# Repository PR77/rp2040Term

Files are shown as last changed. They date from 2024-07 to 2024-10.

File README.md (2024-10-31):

# rp2040Term
PR2040 VT100 Terminal with Parallel TFT LCD. Work in progress!

# Warning
This design has not been compliance tested and will not be. It may cause personal damage to you or others. I take no responsibility for this. I accept no responsibility for any damage to any equipment that results from the use of this design and its components. IT IS ENTIRELY AT YOUR OWN RISK!

# Overview
The main purpose of this design was to learn about the RP2040 scanvideo library components and utilise them with a Parallel TFT LCD. Parallel meaning the interface uses HYSNC, VSYNC, DEN (currently not used), PCLK and RGB[5] signals.

I am currently using this with a Sharp LQ042 LCD with a resolution of 480x272. This works perfectly with a 8x16 Font to give a total of 60 Columns by 17 Rows.

# Appearance Breadboard Version
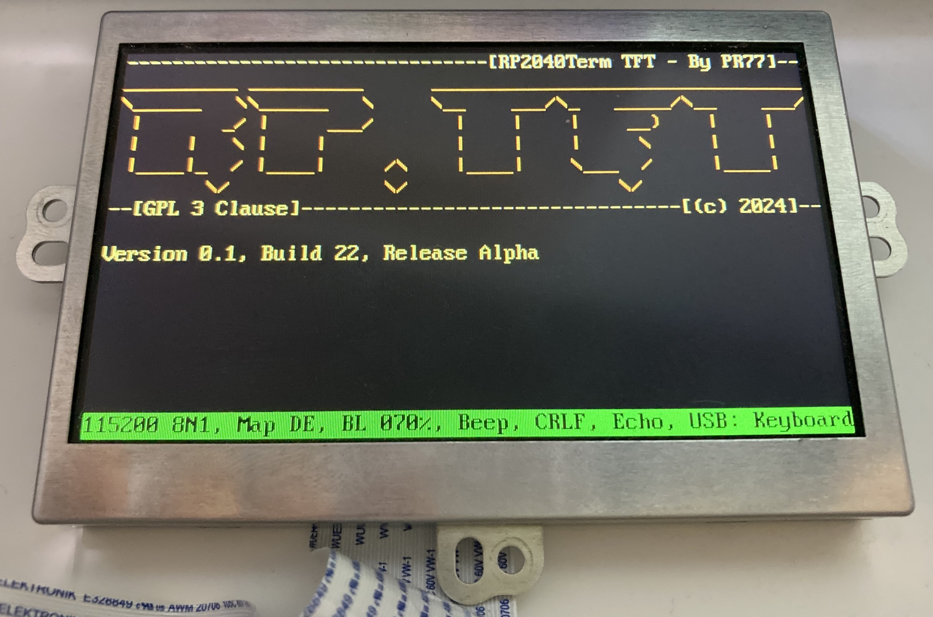
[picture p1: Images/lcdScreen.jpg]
LCD Screen

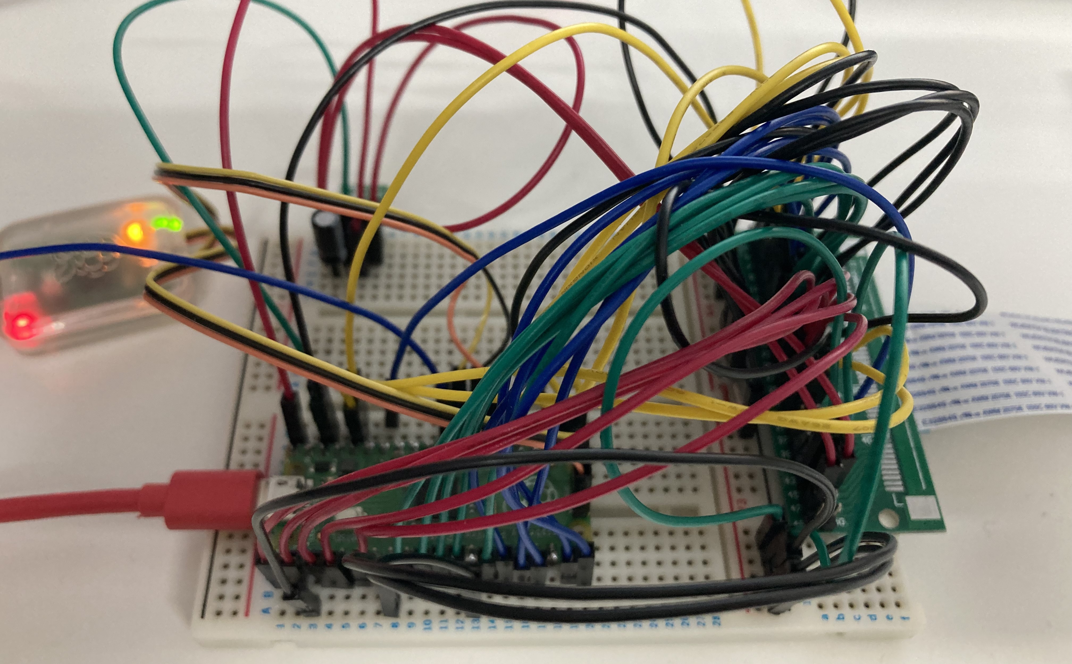
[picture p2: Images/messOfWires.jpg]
Mess Of Wires


# Appearance PCB Version
Here is the 3D render of the general layout. Schematics, gerbers and other support files are now available. A few improvements to the PCB will be made over time, specially I want to add the RP2040 directly to the board and not use a Pi Pico. This iterration is more or less a proof of concept.

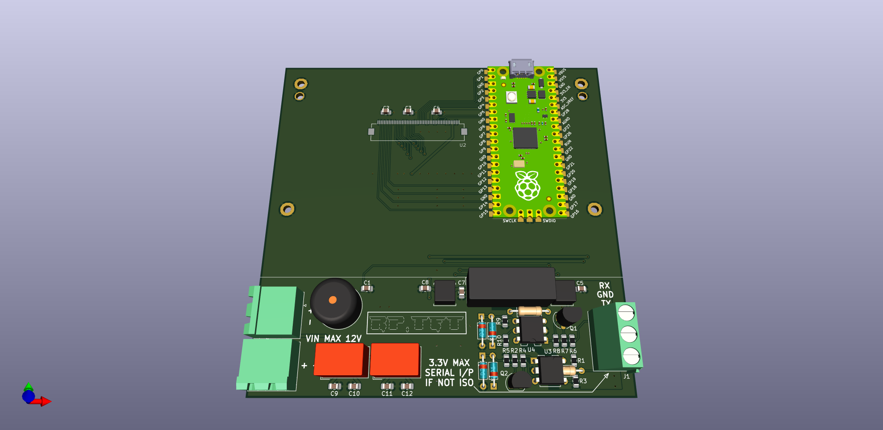
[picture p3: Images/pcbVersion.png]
PCB Layout


# Credits
Repos containing some great tools and resources;
- https://geoffg.net/terminal.html
- https://github.com/Memotech-Bill/pico-colour-text/tree/main
- https://github.com/RC2014Z80/picoterm
- https://github.com/TuriSc/RP2040-PWM-DMA-Audio
- https://github.com/rewtnull/amigafonts
- https://github.com/Jamesits/bin2array

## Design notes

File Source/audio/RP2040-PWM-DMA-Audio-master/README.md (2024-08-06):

# RP2040 PWM/DMA audio

This C library allows playback of audio samples on Raspberry Pi Pico.
It is a fork of Ricardo Massaro's
[pico-audio-demo](https://github.com/moefh/pico-audio-demo), based on an article
by [Greg Chadwick](https://gregchadwick.co.uk/blog/playing-with-the-pico-pt3/).

Please refer to the original code for examples of use.

### Projects using this library
- [Dodepan](https://github.com/TuriSc/Dodepan)

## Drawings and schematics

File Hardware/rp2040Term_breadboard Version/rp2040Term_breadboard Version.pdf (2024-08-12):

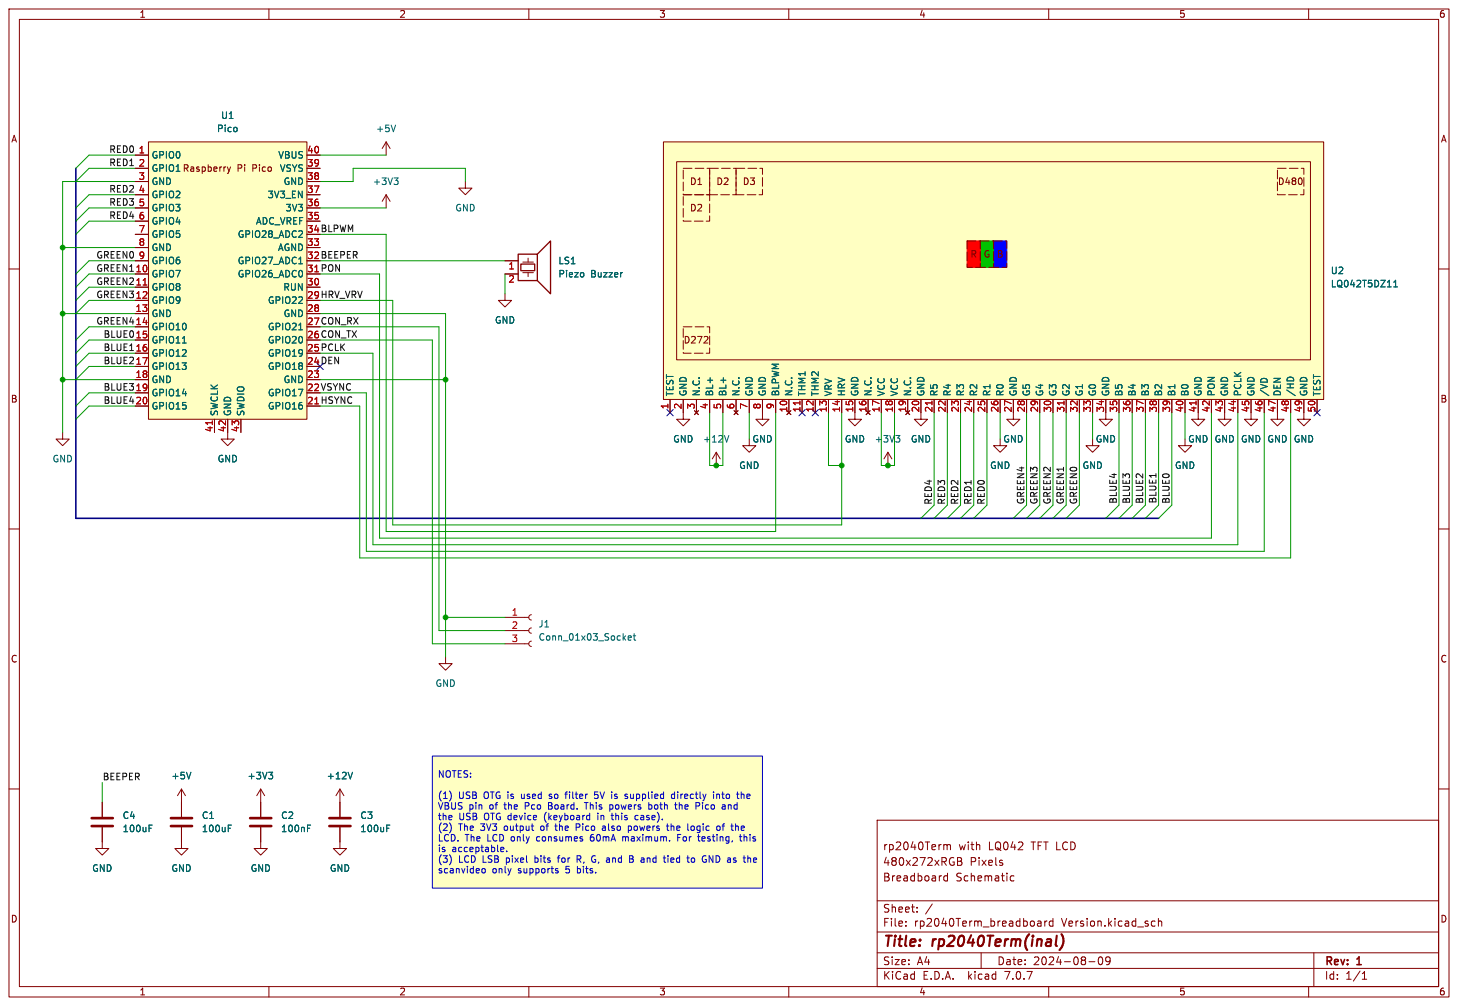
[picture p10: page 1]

1 N.C. 10 THM1 11 THM2 12 VRV 13 HRV 14 GND 15 N.C. 16 VCC 17 VCC 18 N.C. 19 GND

4 B0 40 GND 41 PON 42 GND 43 PCLK 44 GND 45 /VD 46 DEN 47 /HD 48 GND 49 BL+

2 GND 20 R5 21 R4 22 R3 23 R2 24 R1 25 R0 26 GND 27 G5 28 G4 29 N.C. 3 G3 30 G2 31 G1 32 G0 33 GND 34 B5 35 B4 36 B3 37 B2 38 B1 39 BL+

9 GND GND GND GND GND GND GND GND

(2) The 3V3 output of the Pico also powers the logic of the
is acceptable.
(3) LCD LSB pixel bits for R, G, and B and tied to GND as the

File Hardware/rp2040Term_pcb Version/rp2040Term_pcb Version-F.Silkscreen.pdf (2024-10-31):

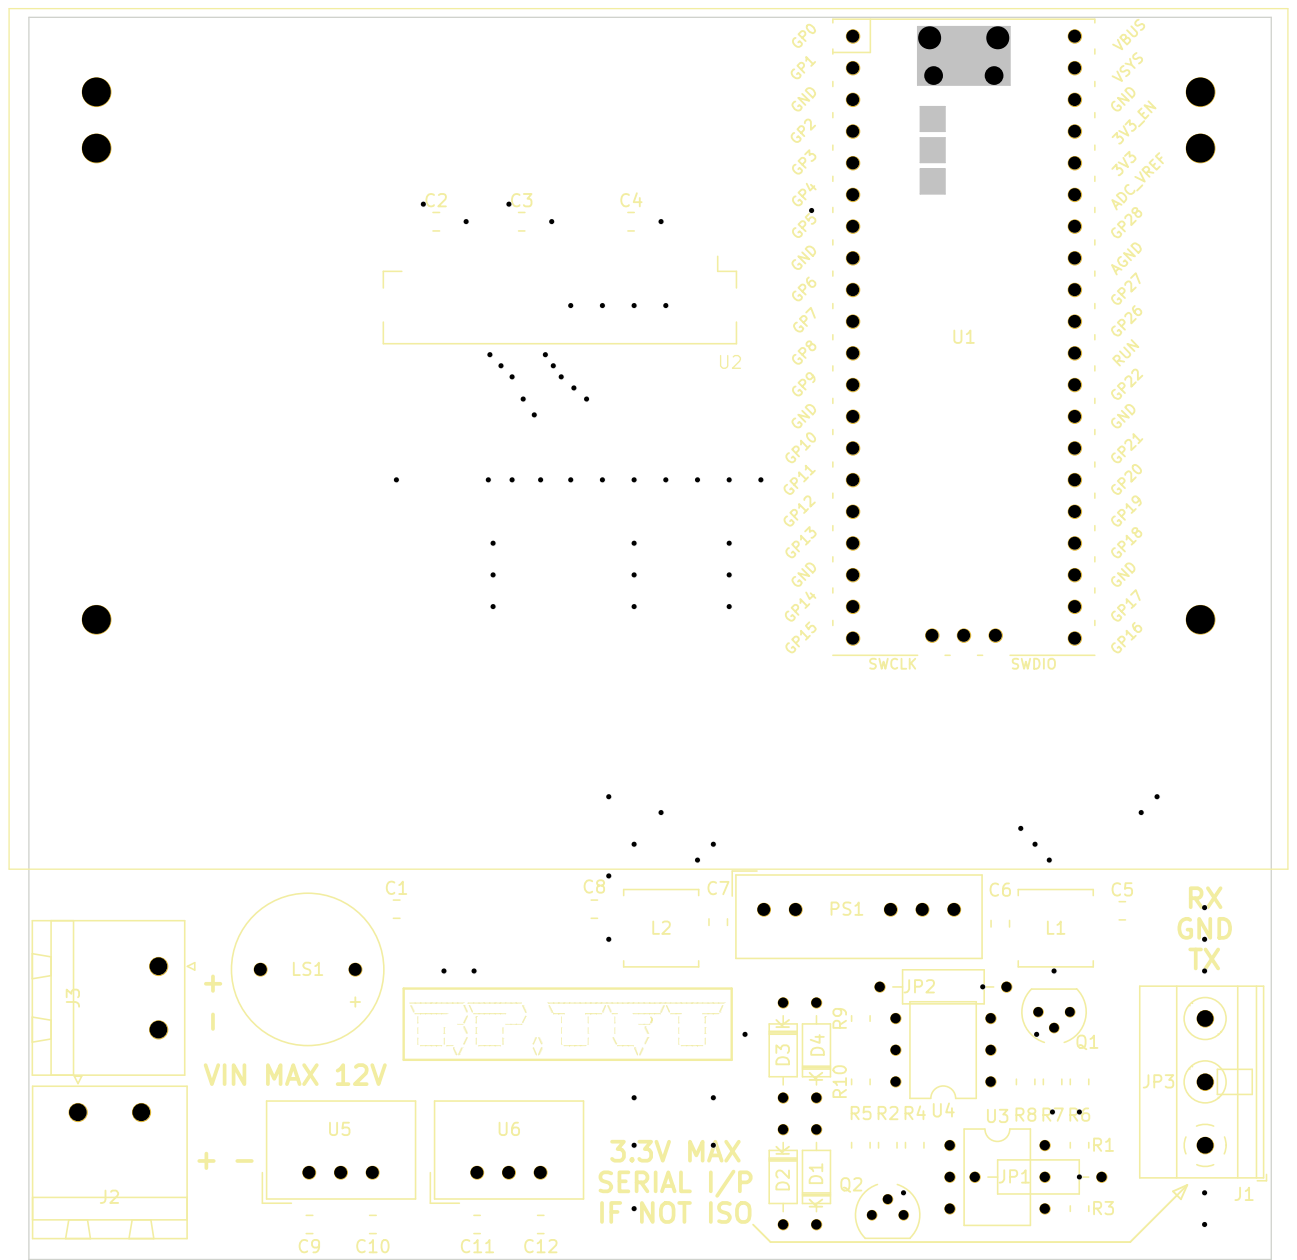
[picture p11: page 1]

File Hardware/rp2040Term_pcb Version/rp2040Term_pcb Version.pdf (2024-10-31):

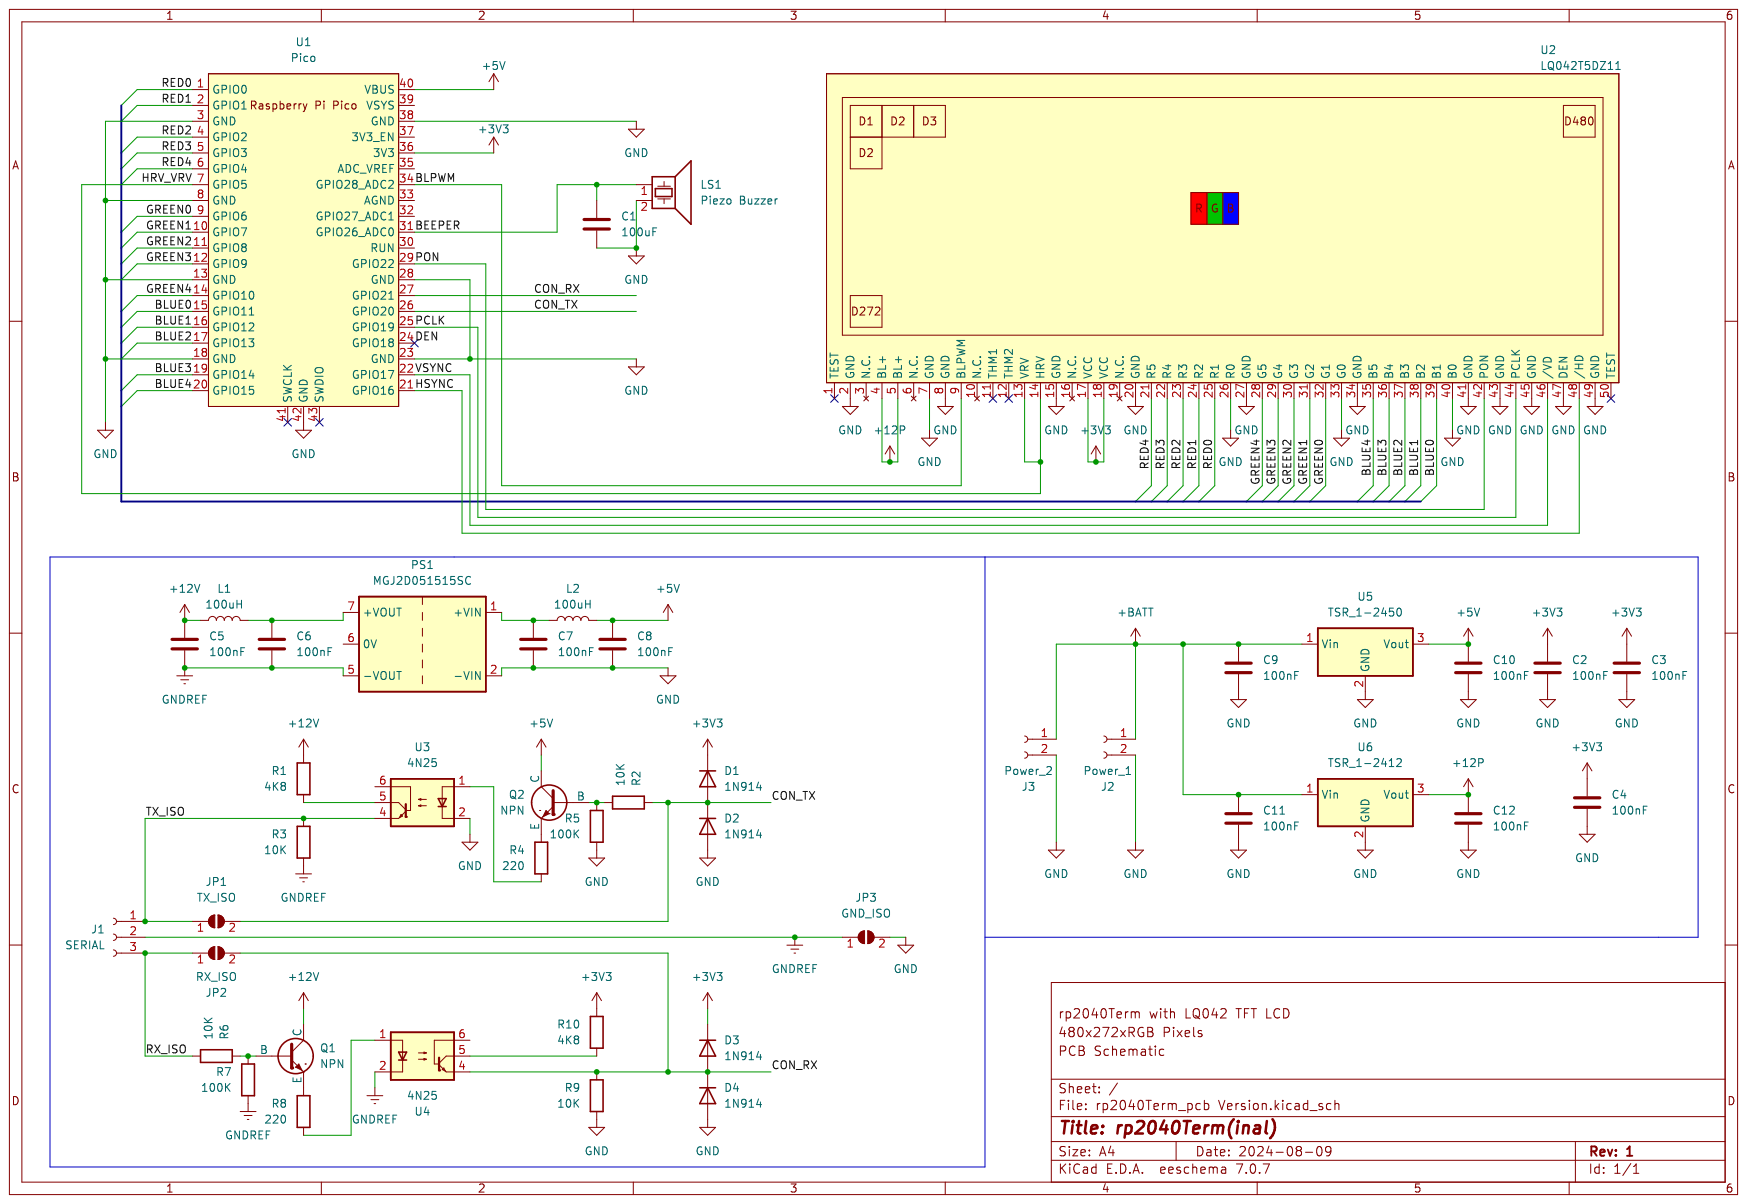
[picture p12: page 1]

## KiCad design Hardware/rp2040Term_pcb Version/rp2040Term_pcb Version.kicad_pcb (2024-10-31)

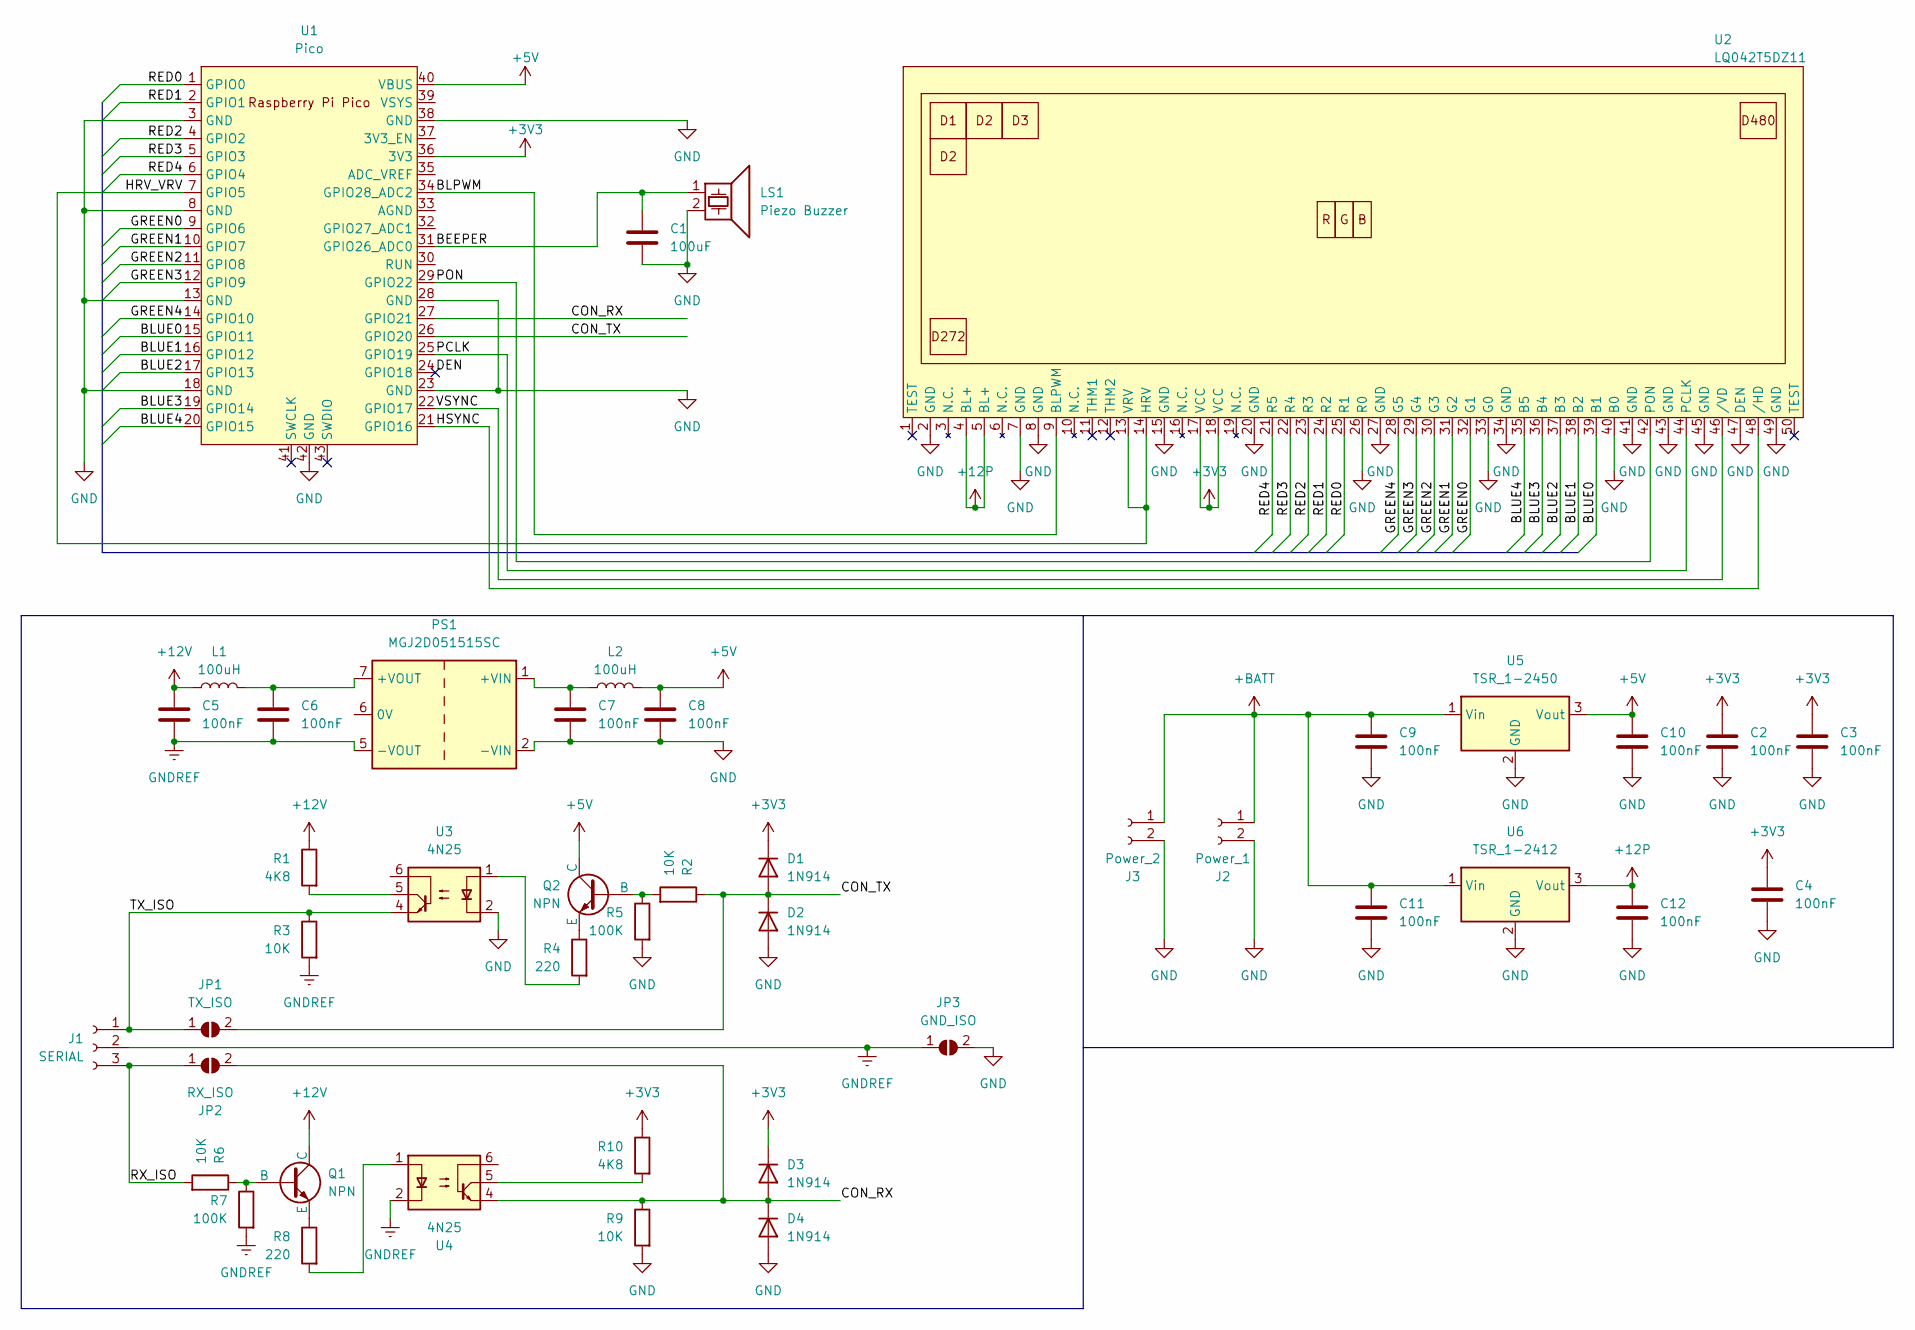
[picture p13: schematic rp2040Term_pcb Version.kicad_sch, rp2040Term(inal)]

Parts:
C1: 100uF; C_0805_2012Metric_Pad1.18x1.45mm_HandSolder
C2, C3, C4, C5, C6, C7, C8, C9, C10, C11, C12: 100nF; C_0805_2012Metric_Pad1.18x1.45mm_HandSolder
D1, D2, D3, D4: 1N914; D_DO-35_SOD27_P7.62mm_Horizontal
J1: SERIAL; TerminalBlock_Phoenix_MKDS-1,5-3-5.08_1x03_P5.08mm_Horizont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
J2: Power_1; PhoenixContact_MSTBA_2,5_2-G-5,08_1x02_P5.08mm_Horizontal
J3: Power_2; PhoenixContact_MSTBA_2,5_2-G-5,08_1x02_P5.08mm_Horizontal
JP1: TX_ISO; R_Axial_DIN0207_L6.3mm_D2.5mm_P10.16mm_Horizontal
JP2: RX_ISO; R_Axial_DIN0207_L6.3mm_D2.5mm_P10.16mm_Horizontal
JP3: GND_ISO; SolderJumper-2_P1.3mm_Open_TrianglePad1.0x1.5mm
L1, L2: 100uH; L_Coilcraft_XAL5050-XXX
LS1: Piezo Buzzer; Buzzer_12x9.5RM7.6
PS1: MGJ2D051515SC; Converter_DCDC_Murata_MGJ2DxxxxxxSC_THT
Q1, Q2: NPN; TO-92L_HandSolder
R1, R10: 4K8; R_0805_2012Metric_Pad1.20x1.40mm_HandSolder
R2, R3, R6, R9: 10K; R_0805_2012Metric_Pad1.20x1.40mm_HandSolder
R4, R8: 220; R_0805_2012Metric_Pad1.20x1.40mm_HandSolder
R5, R7: 100K; R_0805_2012Metric_Pad1.20x1.40mm_HandSolder
U1: Pico; RPi_Pico_SMD_TH
U2: LQ042T5DZ11; LQ042TDZ11
U3, U4: 4N25; DIP-6_W7.62mm
U5: TSR_1-2450; Converter_DCDC_TRACO_TSR-1_THT
U6: TSR_1-2412; Converter_DCDC_TRACO_TSR-1_THT

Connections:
+3V3: C2.1, C3.1, C4.1, D1.1 (K), D3.1 (K), R10.1, U1.36 (3V3), U2.17 (VCC), U2.18 (VCC)
+5V: C8.1, C10.1, L2.2, Q2.1 (C), U1.40 (VBUS), U5.3 (Vout)
+12P: C12.1, U2.4 (BL+), U2.5 (BL+), U6.3 (Vout)
+12V: C5.1, L1.1, Q1.1 (C), R1.1
+BATT: C9.1, C11.1, J2.1, J3.1, U5.1 (Vin), U6.1 (Vin)
/BEEPER: C1.1, LS1.1, U1.31 (GPIO26_ADC0)
/BLPWM: U1.34 (GPIO28_ADC2), U2.9 (BLPWM)
/BLUE0: U1.15 (GPIO11), U2.39 (B1)
/BLUE1: U1.16 (GPIO12), U2.38 (B2)
/BLUE2: U1.17 (GPIO13), U2.37 (B3)
/BLUE3: U1.19 (GPIO14), U2.36 (B4)
/BLUE4: U1.20 (GPIO15), U2.35 (B5)
/CON_RX: D3.2 (A), D4.1 (K), JP2.2 (B), R9.1, U1.27 (GPIO21), U4.4
/CON_TX: D1.2 (A), D2.1 (K), JP1.2 (B), R2.1, U1.26 (GPIO20)
/DEN: U1.24 (GPIO18)
/GREEN0: U1.9 (GPIO6), U2.32 (G1)
/GREEN1: U1.10 (GPIO7), U2.31 (G2)
/GREEN2: U1.11 (GPIO8), U2.30 (G3)
/GREEN3: U1.12 (GPIO9), U2.29 (G4)
/GREEN4: U1.14 (GPIO10), U2.28 (G5)
/HRV_VRV: U1.7 (GPIO5), U2.13 (VRV), U2.14 (HRV)
/HSYNC: U1.21 (GPIO16), U2.48 (/HD)
/PCLK: U1.25 (GPIO19), U2.44 (PCLK)
/PON: U1.29 (GPIO22), U2.42 (PON)
/RED0: U1.1 (GPIO0), U2.25 (R1)
/RED1: U1.2 (GPIO1), U2.24 (R2)
/RED2: U1.4 (GPIO2), U2.23 (R3)
/RED3: U1.5 (GPIO3), U2.22 (R4)
/RED4: U1.6 (GPIO4), U2.21 (R5)
/RX_ISO: J1.3, JP2.1 (A), R6.2
/TX_ISO: J1.1, JP1.1 (A), R3.1, U3.4
/VSYNC: U1.22 (GPIO17), U2.46 (/VD)
GND: C1.2, C2.2, C3.2, C4.2, C7.2, C8.2, C9.2, C10.2, C11.2, C12.2, D2.2 (A), D4.2 (A), J2.2, J3.2, JP3.2 (B), LS1.2, PS1.2 (-VIN), R5.2, R9.2, U1.3 (GND), U1.8 (GND), U1.13 (GND), U1.18 (GND), U1.23 (GND), U1.28 (GND), U1.38 (GND), U1.42 (GND), U2.2 (GND), U2.7 (GND), U2.8 (GND), U2.15 (GND), U2.20 (GND), U2.26 (R0), U2.27 (GND), U2.33 (G0), U2.34 (GND), U2.40 (B0), U2.41 (GND), U2.43 (GND), U2.45 (GND), U2.47 (DEN), U2.49 (GND), U2.MD, U3.2, U5.2 (GND), U6.2 (GND)
GNDREF: C5.2, C6.2, J1.2, JP3.1 (A), PS1.5 (-VOUT), R3.2, R7.2, U4.2
unnamed: C7.1, L2.1, PS1.1 (+VIN)
unnamed: C6.1, L1.2, PS1.7 (+VOUT)
unnamed: Q1.2 (B), R6.1, R7.1
unnamed: Q1.3 (E), R8.1
unnamed: Q2.2 (B), R2.2, R5.1
unnamed: Q2.3 (E), R4.1
unnamed: R1.2, U3.5
unnamed: R4.2, U3.1
unnamed: R8.2, U4.1
unnamed: R10.2, U4.5

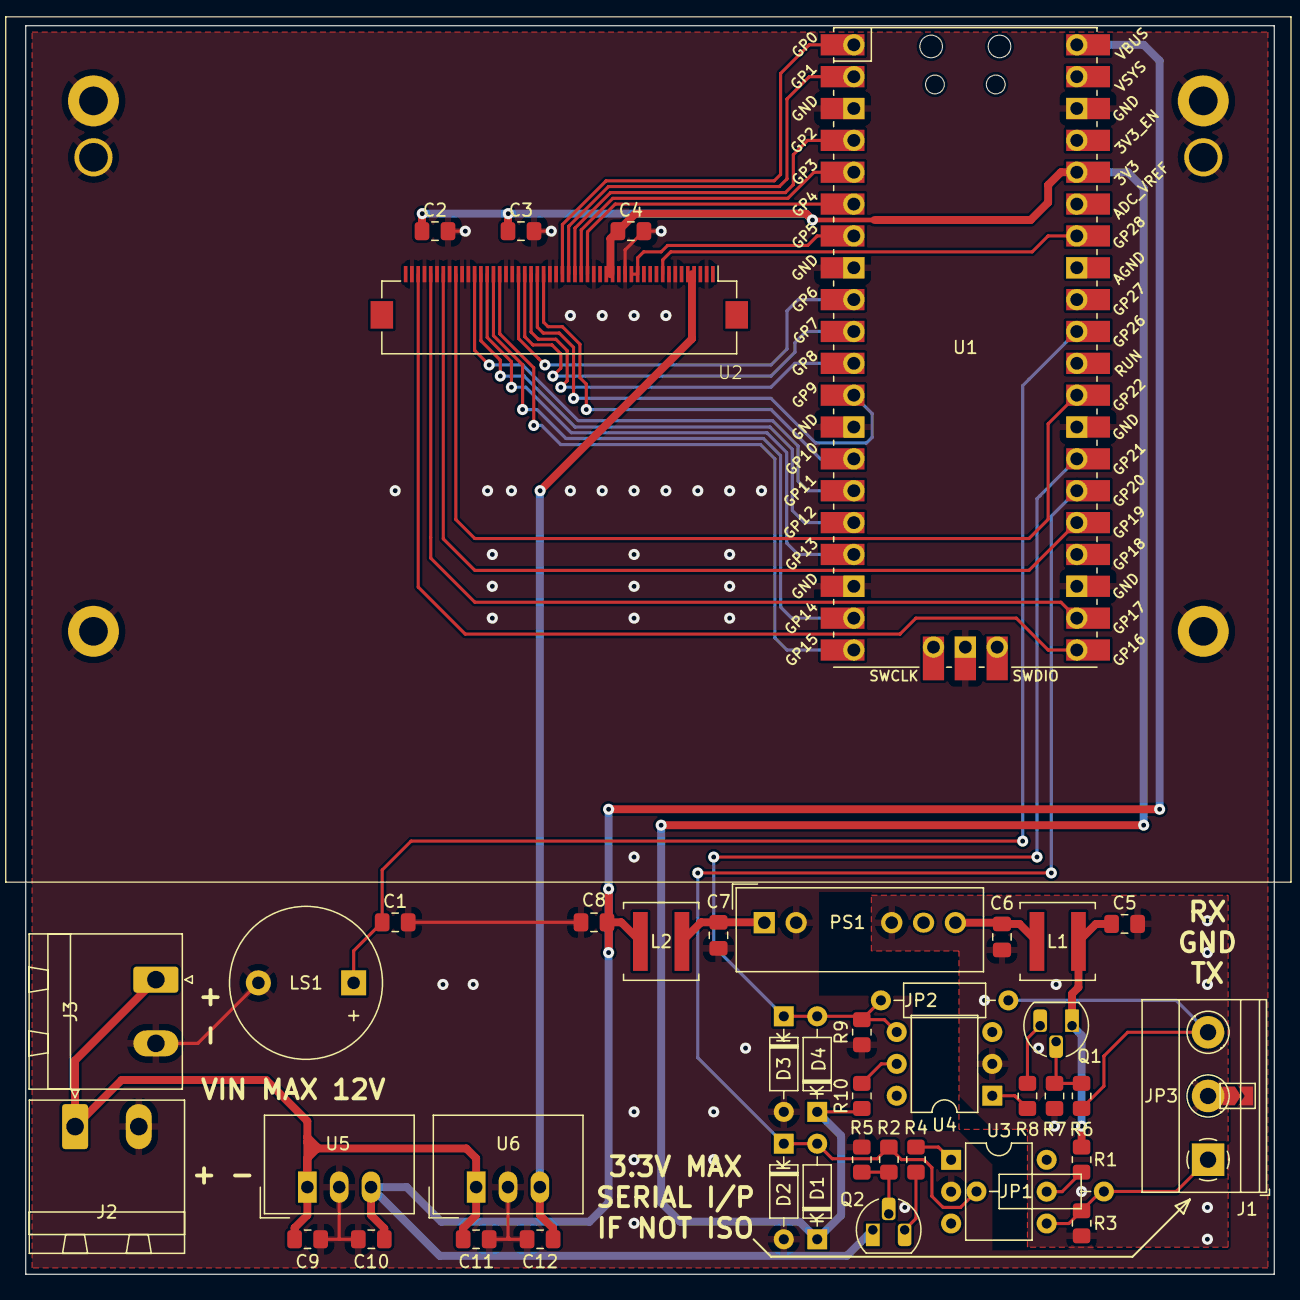
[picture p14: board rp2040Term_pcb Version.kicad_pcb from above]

Board: 2 copper layers, 99.6 x 99.6 mm, 44 parts (0 on the bottom side), 43 nets.

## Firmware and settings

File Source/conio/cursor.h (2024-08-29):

#ifndef CONIO_CURSOR_H
#define	CONIO_CURSOR_H

#include "pico.h"
#include "pico/stdlib.h"
#include "pico/scanvideo.h"
#include "pico/scanvideo/composable_scanline.h"

#define DEFAULT_CURSOR_POSITION_STEPS   1
#define DEFAULT_CURSOR_TAB_STEPS        4
#define CURSOR_FLASH_INTERVAL_MS        525

typedef struct {
    uint8_t             currentCursorRow;
    uint8_t             currentCursorColumn;
    bool                cursorIsVisible;
    bool                cursorBlinkState;
} st_conioCursor;

void conio_initialiseCursorBuffer(void);
st_conioCursor *conio_getCurrentCursorPosition(void);
void conio_setNewCursorPosition(uint8_t rowIndex, uint8_t columnIndex);

/* Cursor functions */
void conio_refreshCursor(void);
void conio_enableCursor(void);
void conio_disableCursor(void);
void conio_displayCursor(void);
void conio_hideCursor(void);
void conio_moveCursorHome(void);
void conio_moveCursorUp(uint8_t positionCounts);
void conio_moveCursorDown(uint8_t positionCounts);
void conio_moveCursorLeft(uint8_t positionCounts);
void conio_moveCursorRight(uint8_t positionCounts);
void conio_updateCursorTask(void);

#endif // CONIO_CURSOR_H

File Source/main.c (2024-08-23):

/*  main.c - The main program -------------------------------------------------
__________ __________      _________________________________
\______   \\______   \     \__    ___/\_   _____/\__    ___/
 |       _/ |     ___/       |    |    |    __)    |    |   
 |    |   \ |    |           |    |    |     \     |    |   
 |____|_  / |____|     /\    |____|    \___  /     |____|   
        \/             \/                  \/               
https://patorjk.com/software/taag/#p=display&h=0&v=0&f=Graffiti

RP2040 Terminal Emulator for parallel RBG666 TFT Display using the RP2040
scanvideo library. I used bits-and-pieces for these awesome repos to develop
this;

https://geoffg.net/terminal.html
https://github.com/Memotech-Bill/pico-colour-text/tree/main
https://github.com/RC2014Z80/picoterm
https://github.com/rewtnull/amigafonts
https://github.com/Jamesits/bin2array

-----------------------------------------------------------------------------*/

#include "pico.h"
#include "pico/stdlib.h"
#include "pico/scanvideo.h"
#include "pico/scanvideo/composable_scanline.h"
#include "pico/multicore.h"
#include "tusb.h"
#include "class/hid/hid.h"
#include "main.h"
#include "conio.h"
#include "popup.h"
#include "cursor.h"
#include "serial.h"
#include "status.h"
#include "keyboard.h"
#include "system.h"
#include "font.h"
#include "vt100.h"
#include "build_number.h"

static semaphore_t videoInitialised;

void main_initialiseScanVideo(void) {

    scanvideo_setup(&tftLQ042_480x272_60);
    scanvideo_timing_enable(true);
    sem_release(&videoInitialised);
    system_renderLoop();
}

int main(void) {

    char msgBuffer[TEXT_COLUMNS_VISIBLE];

    /* PLL Calculations --> python vcocalc.py 123.5
    Requested: 123.5 MHz
    Achieved: 123.5 MHz
    REFDIV: 2
    FBDIV: 247 (VCO = 1482.0 MHz)
    PD1: 6
    PD2: 2
    */
    set_sys_clock_pll(1482000000, 6, 2);

    system_initialiseSystem();
    conio_initialiseCharacterBuffer(PALETTE_COLOUR_AMBER_INDEX, PALETTE_COLOUR_BLACK_INDEX);
    conio_initialiseCursorBuffer();
    conio_initialisePopupBuffer();
    status_initialiseStatusBar(PALETTE_COLOUR_GREEN_INDEX, PALETTE_COLOUR_BLACK_INDEX, true);

    serial_initialiseTerminalUart(uart1);
    serial_attachReceivedCharacterHandler(&vt100_putCharacter);

    keyboard_initialiseKeyboard();
    keyboard_attachSystemResetHandler(&system_executeSystemReset);
    keyboard_attachCustomKeyHandler(HID_KEY_F1, &conio_clearScreenHomeCursor, NULL);
    keyboard_attachCustomKeyHandler(HID_KEY_F2, &font_cycleDisplayFont, NULL);
    keyboard_attachCustomKeyHandler(HID_KEY_F8, &system_toggleBeeper, NULL);
    keyboard_attachCustomKeyHandler(HID_KEY_F9, &system_toggleCRLF, NULL);
    keyboard_attachCustomKeyHandler(HID_KEY_F10, &system_decreaseBacklightByStep, NULL);
    keyboard_attachCustomKeyHandler(HID_KEY_F11, &system_toggleLocalEcho, NULL);
    keyboard_attachCustomKeyHandler(HID_KEY_F12, &system_increaseBacklightByStep, NULL);
    keyboard_attachDefaultKeyHandler(&system_handleKeyboardAndUartTransmitRouting, NULL);
    
    // Create a semaphore to be posted when video init is complete
    sem_init(&videoInitialised, 0, 1);
    multicore_launch_core1(main_initialiseScanVideo);
    // wait for initialization of video to be complete
    sem_acquire_blocking(&videoInitialised);

    // Audio playback needs to be initialised after scanvideo due to DMA assignments.
    // Scanvideo requires DMA Channels 0 + 1, and will fail if not available.
    system_initialiseAudioPlayer();

	//                 012345678901234567890123456789012345678901234567890123456789
	//                 |        |         |         |         |         |         |
    conio_printString("--------------------------------[RP2040Term TFT - By PR77]--", PALETTE_COLOUR_YELLOW_INDEX, PALETTE_COLOUR_BLACK_INDEX);
    conio_printString("__________ __________      _________________________________", PALETTE_COLOUR_AMBER_INDEX, PALETTE_COLOUR_BLACK_INDEX);
    conio_printString("\\______   \\\\______   \\     \\__    ___/\\_   _____/\\__    ___/", PALETTE_COLOUR_AMBER_INDEX, PALETTE_COLOUR_BLACK_INDEX);
    conio_printString(" |       _/ |     ___/       |    |    |    __)    |    |\r\n", PALETTE_COLOUR_AMBER_INDEX, PALETTE_COLOUR_BLACK_INDEX);   
    conio_printString(" |    |   \\ |    |           |    |    |     \\     |    |\r\n", PALETTE_COLOUR_AMBER_INDEX, PALETTE_COLOUR_BLACK_INDEX);   
    conio_printString(" |____|_  / |____|     /\\    |____|    \\___  /     |____|\r\n", PALETTE_COLOUR_AMBER_INDEX, PALETTE_COLOUR_BLACK_INDEX);   
    conio_printString("        \\/             \\/                  \\/\r\n", PALETTE_COLOUR_AMBER_INDEX, PALETTE_COLOUR_BLACK_INDEX);               

	//                 012345678901234567890123456789012345678901234567890123456789
	//                 |        |         |         |         |         |         |
    conio_printString("--[GPL 3 Clause]--------------------------------[(c) 2024]--", PALETTE_COLOUR_YELLOW_INDEX, PALETTE_COLOUR_BLACK_INDEX);
    conio_printString("\r\n", PALETTE_COLOUR_WHITE_INDEX, PALETTE_COLOUR_BLACK_INDEX);

    //                 012345678901234567890123456789012345678901234567890123456789
	//                 |        |         |         |         |         |         |
    snprintf(msgBuffer, TEXT_COLUMNS_VISIBLE, "Version %s, Build %d, Release %s\r\n", CMAKE_PROJECT_VERSION, BUILD_NUMBER, CMAKE_PROJECT_DESCRIPTION);
    conio_printString(msgBuffer, PALETTE_COLOUR_YELLOW_INDEX, PALETTE_COLOUR_BLACK_INDEX);
    conio_enableCursor();

    while (true) {
        system_updateLedTask();
        conio_updateCursorTask();
        conio_updatePopupTask();
        status_updateStatusBarTask();
        keyboard_updateKeyboardTask();
        system_updateBellTask();
    }
}

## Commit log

2024-07-19 Updates
    Added support for a fixed Status Bar on the last row of the screen.
    [main.c, status.c]
2024-07-19 Updates
    Added PWM Backlight dimming and framework for USB Keyboard support.
2024-07-21 Updates
    Auto CRLF added when cursor is at TEXT_COLUMNS_VISIBLE. Additionally, this fixes bug where first character of status bar invert attribute would be removed as the cursor would overwrite this.
    [main.c]
2024-07-22 Updates
    Starting working on USB interface. Status bar now shows when USB device is connected.
2024-08-02 Updates
    Added support for UART transmit, CTRL-ALT-DEL system reset and more conio functions.
    [main.c, serial.c, status.c]
2024-08-02 Updates
    Support for local echo and combined key handler for conio printing and UART transmission.
2024-08-03 Updates
    Added UART receive handler interface to move conio calls out of the serial interface module. This is now mapped during initialisation / routing configuration.
2024-08-12 Updates
    Added breadboard version schematic.
    [rp2040Term_breadboard Version.kicad_pcb, rp2040Term_breadboard Version.kicad_sch]
2024-08-12 Updates
    Added missing Piezo to schematic.
    [rp2040Term_breadboard Version.kicad_sch]
2024-08-16 Updates
    Renamed RP2040-PWM-DMA-Audio directory.
2024-08-27 Updates
    Updated conio handler to allow printing of extended ASCII characters.
2024-10-03 Updates
    Added pin assignment updates for PCB version.
2024-10-28 Updates
    Added support for picotool pin identification.
2024-10-31 Updates
    Added PCB layout.
    [rp2040Term_pcb Version-B_Cu.gbr, rp2040Term_pcb Version-B_Mask.gbr, rp2040Term_pcb Version-B_Paste.gbr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]
